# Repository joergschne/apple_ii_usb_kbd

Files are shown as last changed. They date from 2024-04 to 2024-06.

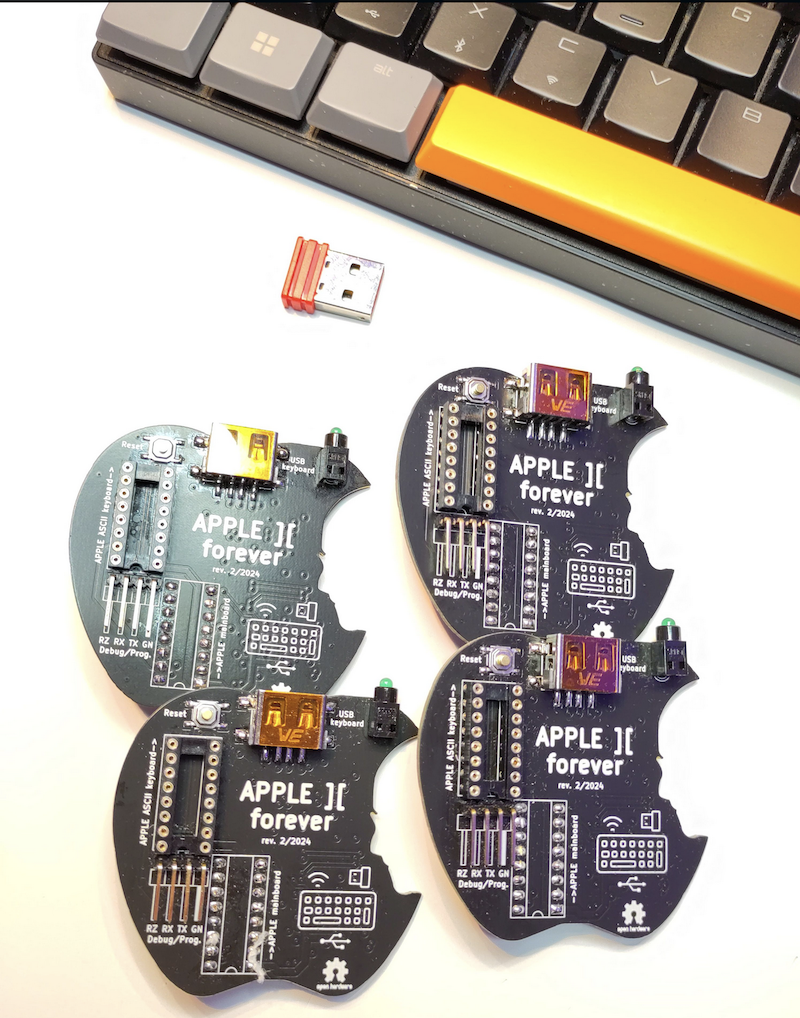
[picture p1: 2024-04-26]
Pictures/produced.png

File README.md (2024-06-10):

# Apple II USB Keyboard-Adapter

Based on Arduino-UNO (ATMEGA328P) and Maxim MAX3421E USB-Host-Controller

- USB keyboard (wireless) with and without NKRO (N-Key-Rollover) support.

- DE and US layouts can be toggled by pressing Windows+1 (US) and Windows+2 (DE). Windows+0 stores the last setting in EEPROM.

- Ctrl+Insert / Ctrl+Alt+Delete performs a hardware reset.

- The Windows key itself switches back to the original Apple keyboard. This is the default setting on power up and the switch to USB is automatic.

- Autorepeat function and the “Up arrow” button repeats the last entry

- Caps Lock (Shift Lock) lower case support

- Win+9 (LodeRunner Mapping) assigns the keys I,J,K,L to W,A,S,D to play an unpatched version of LodeRunner with the usual key combination

- Specially build for: CHERRY MX-LP 2.1 Compact Wireless Keyboard

APPLE II forever! 

Apple

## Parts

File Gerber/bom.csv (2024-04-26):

Designator | Footprint | Quantity | Value | LCSC Part #
C1, C2 | 0805 | 2 | 10uF
C10, C9 | 0805 | 2 | 18pF
C3, C6, C7, C8 | 0805 | 4 | 100n
C4, C5 | 0805 | 2 | 22pF
D1 | LED_D3.0mm | 1 | LED
F1 | 0805 | 1 | 0.75A
J1 | USB-A 629104190121 | 1 | USB-A 629104190121
J2 | PinHeader_1x04_P2.54mm_Horizontal | 1 | Debug
R1, R8, R9 | 0805 | 3 | 2K2
R2, R3 | 0805 | 2 | 33
R4, R5, R6 | 0805 | 3 | 10k
R7 | 0805 | 1 | 100
SW1 | SW_PTS525SM15SMTR2LFS | 1 | Reset
U1 | DIP-16_W7.62mm_Socket_LongPads | 1 | MAINBOARD (OUT)
U2 | DIP-16_W7.62mm_Socket_LongPads | 1 | KEYBOARD (IN)
U3, U4 | SOIC-16_3.9x9.9mm_P1.27mm | 2 | 74x257
U5 | SOIC-16_3.9x9.9mm_P1.27mm | 1 | 74x4050
U6 | TQFP-32_7x7mm_P0.8mm | 1 | ATMEGA328-TQFP
U7 | max3421-TQFP | 1 | USB-Host Controller
U8 | SOT-23 | 1 | MCP1700x-3V3
Y1 | FA238 | 1 | 12Mhz
Y2 | FA238 | 1 | 16Mhz

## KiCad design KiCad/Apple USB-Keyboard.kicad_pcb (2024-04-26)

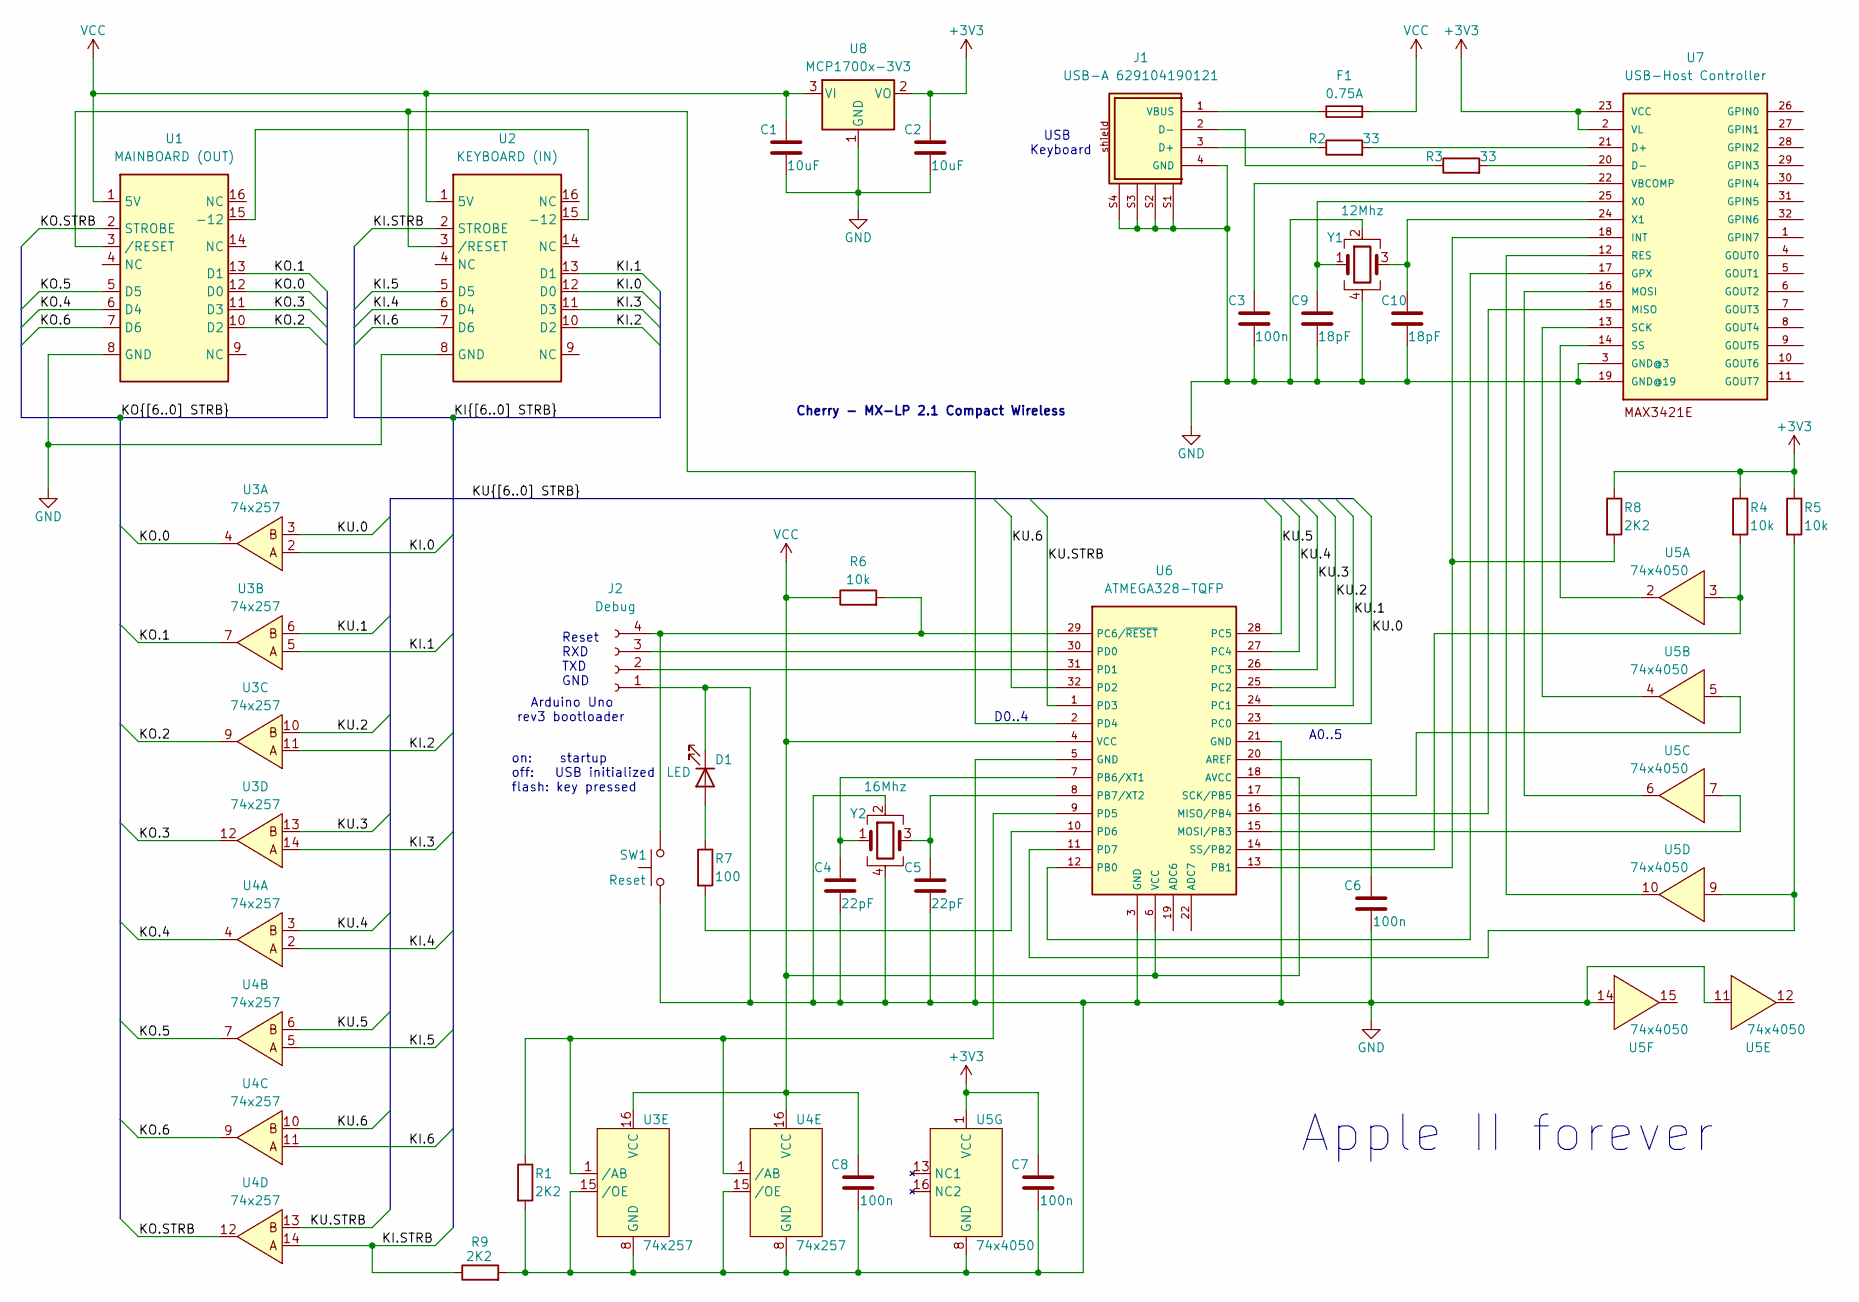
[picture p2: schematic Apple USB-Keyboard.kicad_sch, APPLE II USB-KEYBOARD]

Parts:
C1, C2: 10uF; C_0805_2012Metric_Pad1.18x1.45mm_HandSolder
C3, C6, C7, C8: 100n; C_0805_2012Metric_Pad1.18x1.45mm_HandSolder
C4, C5: 22pF; C_0805_2012Metric_Pad1.18x1.45mm_HandSolder
C9, C10: 18pF; C_0805_2012Metric_Pad1.18x1.45mm_HandSolder
D1: LED; LED_D3.0mm
F1: 0.75A; Fuse_0805_2012Metric_Pad1.15x1.40mm_HandSolder
J1: USB-A 629104190121; PART-NUMBER 629104190121
J2: Debug; PinHeader_1x04_P2.54mm_Horizontal
R1, R8, R9: 2K2; R_0805_2012Metric_Pad1.20x1.40mm_HandSolder
R2, R3: 33; R_0805_2012Metric_Pad1.20x1.40mm_HandSolder
R4, R5, R6: 10k; R_0805_2012Metric_Pad1.20x1.40mm_HandSolder
R7: 100; R_0805_2012Metric_Pad1.20x1.40mm_HandSolder
SW1: Reset; SW_PTS525SM15SMTR2LFS
U1: MAINBOARD (OUT); DIP-16_W7.62mm_Socket_LongPads
U2: KEYBOARD (IN); DIP-16_W7.62mm_Socket_LongPads
U3, U4: 74x257; SOIC-16_3.9x9.9mm_P1.27mm
U5: 74x4050; SOIC-16_3.9x9.9mm_P1.27mm
U6: ATMEGA328-TQFP; TQFP-32_7x7mm_P0.8mm
U7: USB-Host Controller; max3421-TQFP
U8: MCP1700x-3V3; SOT-23
Y1: 12Mhz; FA238
Y2: 16Mhz; FA238

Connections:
+3V3: C2.1, C7.2, R4.1, R5.1, R8.1, U5.1 (VCC), U7.2 (VL), U7.23 (VCC), U8.2 (VO)
/KI.0: U2.12 (D0), U3.2
/KI.1: U2.13 (D1), U3.5
/KI.2: U2.10 (D2), U3.11
/KI.3: U2.11 (D3), U3.14
/KI.4: U2.6 (D4), U4.2
/KI.5: U2.5 (D5), U4.5
/KI.6: U2.7 (D6), U4.11
/KI.STRB: R9.1, U2.2 (STROBE), U4.14
/KO.0: U1.12 (D0), U3.4
/KO.1: U1.13 (D1), U3.7
/KO.2: U1.10 (D2), U3.9
/KO.3: U1.11 (D3), U3.12
/KO.4: U1.6 (D4), U4.4
/KO.5: U1.5 (D5), U4.7
/KO.6: U1.7 (D6), U4.9
/KO.STRB: U1.2 (STROBE), U4.12
/KU.0: U3.3, U6.23 (PC0)
/KU.1: U3.6, U6.24 (PC1)
/KU.2: U3.10, U6.25 (PC2)
/KU.3: U3.13, U6.26 (PC3)
/KU.4: U4.3, U6.27 (PC4)
/KU.5: U4.6, U6.28 (PC5)
/KU.6: U4.10, U6.32 (PD2)
/KU.STRB: U4.13, U6.1 (PD3)
GND: C1.2, C2.2, C3.2, C4.2, C5.2, C6.1, C7.1, C8.1, C9.2, C10.2, D1.1 (K), J1.4 (GND), J1.S1, J1.S2, J1.S3, J1.S4, J2.1, R1.2, R9.2, SW1.1, U1.8 (GND), U2.8 (GND), U3.8 (GND), U3.15 (/OE), U4.8 (GND), U4.15 (/OE), U5.8 (GND), U5.11, U5.14, U6.3 (GND), U6.5 (GND), U6.21 (GND), U7.3 (GND@3), U7.19 (GND@19), U8.1 (GND), Y1.2, Y1.4, Y2.2, Y2.4
unnamed: D1.2 (A), R7.1
unnamed: J1.3 (D+), R2.1
unnamed: J1.2 (D-), R3.1
unnamed: F1.1, J1.1 (VBUS)
unnamed: J2.2, U6.31 (PD1)
unnamed: J2.3, U6.30 (PD0)
unnamed: J2.4, R6.2, SW1.2, U6.29 (PC6/~RESET)
unnamed: U1.15 (-12), U2.15 (-12)
unnamed: U1.3 (/RESET), U2.3 (/RESET), U6.2 (PD4)
unnamed: R1.1, U3.1 (/AB), U4.1 (/AB), U6.9 (PD5)
unnamed: C6.2, U6.20 (AREF)
unnamed: U6.16 (MISO/PB4), U7.15 (MISO)
unnamed: U5.7, U6.15 (MOSI/PB3)
unnamed: U6.12 (PB0), U7.17 (GPX)
unnamed: R8.2, U6.13 (PB1), U7.18 (INT)
unnamed: C4.1, U6.7 (PB6/XT1), Y2.1
unnamed: C5.1, U6.8 (PB7/XT2), Y2.3
unnamed: R7.2, U6.10 (PD6)
unnamed: R5.2, U5.9, U6.11 (PD7)
unnamed: U5.5, U6.17 (SCK/PB5)
unnamed: R4.2, U5.3, U6.14 (SS/PB2)
unnamed: R2.2, U7.21 (D+)
unnamed: R3.2, U7.20 (D-)
unnamed: U5.6, U7.16 (MOSI)
unnamed: U5.10, U7.12 (RES)
unnamed: U5.4, U7.13 (SCK)
unnamed: U5.2, U7.14 (SS)
unnamed: C3.1, U7.22 (VBCOMP)
unnamed: C9.1, U7.25 (X0), Y1.1
unnamed: C10.1, U7.24 (X1), Y1.3
VCC: C1.1, C8.2, F1.2, R6.1, U1.1 (5V), U2.1 (5V), U3.16 (VCC), U4.16 (VCC), U6.4 (VCC), U6.6 (VCC), U6.18 (AVCC), U8.3 (VI)

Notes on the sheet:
D0..4
A0..5
Cherry - MX-LP 2.1 Compact Wireless
USB Keyboard
Arduino Uno rev3 bootloader
Reset RXD TXD GND
on: startup off: USB initialized flash: key pressed
Apple II forever

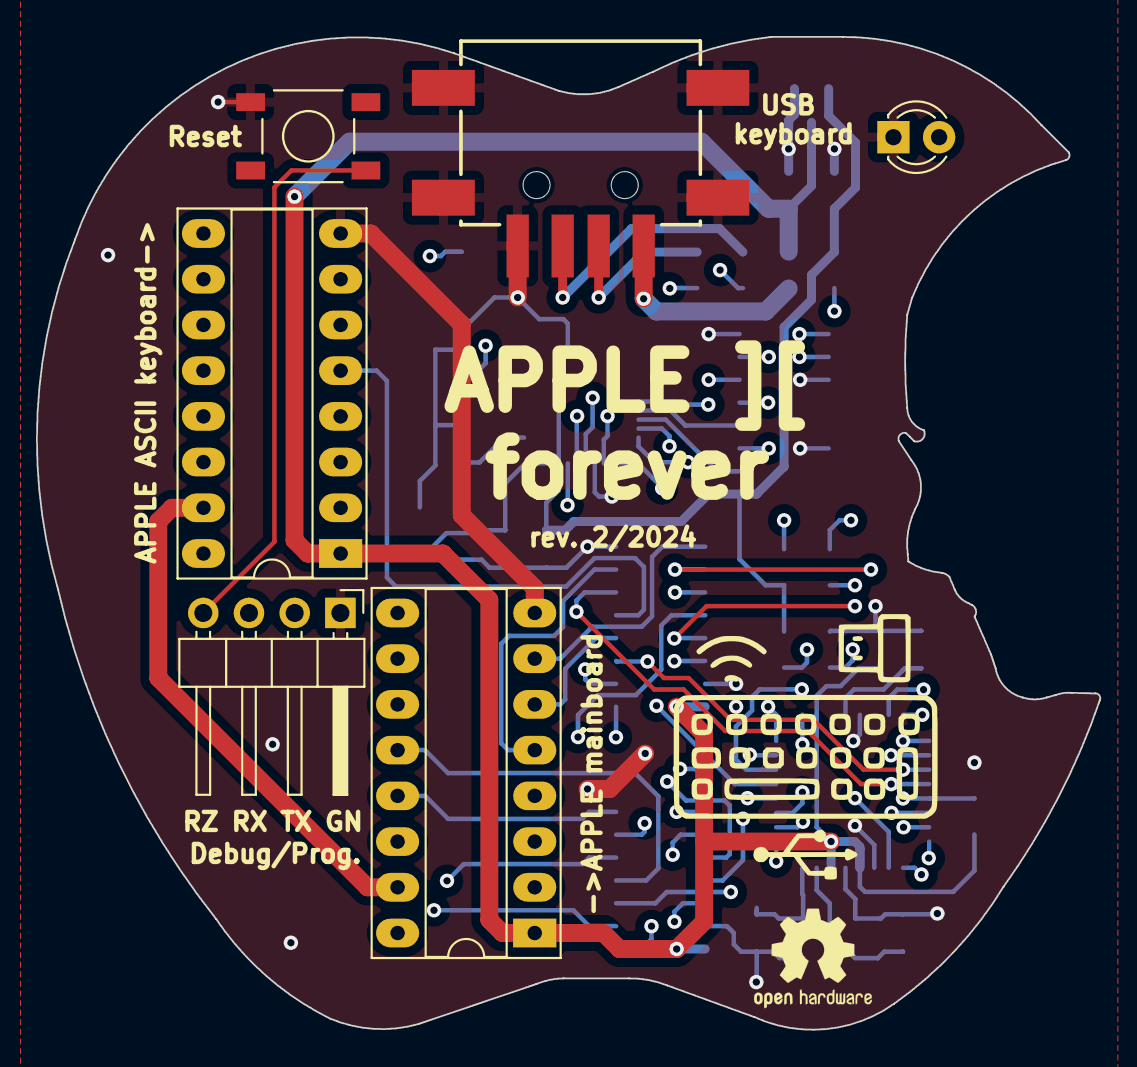
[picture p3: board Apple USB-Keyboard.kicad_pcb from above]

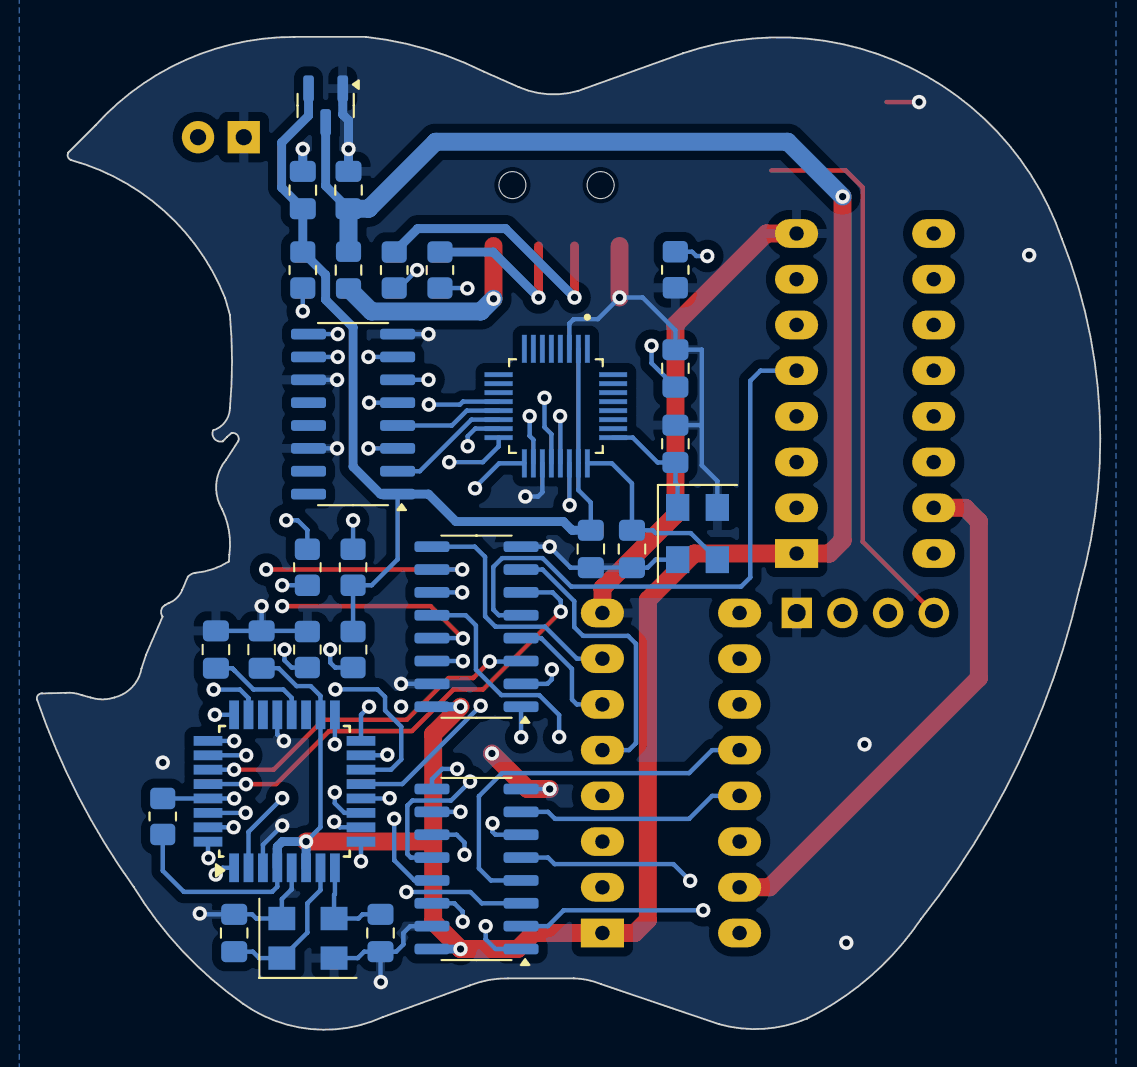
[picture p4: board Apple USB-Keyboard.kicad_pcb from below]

Board: 4 copper layers, 59.1 x 55.2 mm, 34 parts (28 on the bottom side), 57 nets.

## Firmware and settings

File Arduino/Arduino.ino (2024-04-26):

/*
           _____  _____  _____  _      ______   _____ _____ 
      /\   |  __ \|  __ \|  __ \| |    |  ____| |_   _|_   _|
     /  \  | |__) | |__) | |__) | |    | |__      | |   | |  
    / /\ \ |  ___/|  ___/|  ___/| |    |  __|     | |   | |  
   / ____ \| |    | |    | |    | |____| |____   _| |_ _| |_ 
  /_/  __\_\_|____|_|____|_|____|______|______|_|_____|_____|
      |  ____/ __ \|  __ \|  ____\ \    / /  ____|  __ \     
      | |__ | |  | | |__) | |__   \ \  / /| |__  | |__) |    
      |  __|| |  | |  _  /|  __|   \ \/ / |  __| |  _  /     
      | |   | |__| | | \ \| |____   \  /  | |____| | \ \     
      |_|    \____/|_|  \_\______|   \/   |______|_|  \_\    

   APPLE ][ USB-Dual-Keyboard-Adapter (Arduino UNO ATMEAG328P)
                      Version: 04/2024
*/

#include <hidcomposite.h>
#include <usbhub.h>
#include <avr/pgmspace.h>
#include <EEPROM.h>
#include <SPI.h>

#include "Simpletimer.h"

#include "keyboard_encoder.h"
#include "keyboard_decoder.h"

#define PrintDebugInfo true
#define DefaultKeyboardLayout 2 // 1=US 2=DE
#define maxLayout 2

#define REPEAT_INTERVAL_MS 80
#define REPEAT_DELAY 8
#define MAX_REPEAT_BUFFER 64

const char string_0[] PROGMEM = "            _____  _____  _____  _      ______   _____ _____ ";
const char string_1[] PROGMEM = "      /\\   |  __ \\|  __ \\|  __ \\| |    |  ____| |_   _|_   _|";
const char string_2[] PROGMEM = "     /  \\  | |__) | |__) | |__) | |    | |__      | |   | |  ";
const char string_3[] PROGMEM = "    / /\\ \\ |  ___/|  ___/|  ___/| |    |  __|     | |   | |  ";
const char string_4[] PROGMEM = "   / ____ \\| |    | |    | |    | |____| |____   _| |_ _| |_ ";
const char string_5[] PROGMEM = "  /_/  __\\_\\_|____|_|____|_|____|______|______|_|_____|_____|";
const char string_6[] PROGMEM = "      |  ____/ __ \\|  __ \\|  ____\\ \\    / /  ____|  __ \\     ";
const char string_7[] PROGMEM = "      | |__ | |  | | |__) | |__   \\ \\  / /| |__  | |__) |    ";
const char string_8[] PROGMEM = "      |  __|| |  | |  _  /|  __|   \\ \\/ / |  __| |  _  /     ";
const char string_9[] PROGMEM = "      | |   | |__| | | \\ \\| |____   \\  /  | |____| | \\ \\     ";
const char string_A[] PROGMEM = "      |_|    \\____/|_|  \\_\\______|   \\/   |______|_|  \\_\\    ";
const char *const string_table[] PROGMEM = { string_0, string_1, string_2, string_3, string_4, string_5, string_6, string_7, string_8, string_9, string_A };
char buffer[80]; // make sure this is large enough for the largest string it must hold

uint8_t repeatBuffer[MAX_REPEAT_BUFFER] = {};

uint8_t lastKeyPressed = 0;
uint8_t repeatDelay = REPEAT_DELAY;
uint8_t repeatBufferIndex = 0;

boolean lodeRunnerMapping = false;

KeyEncoder KeyEncoder;
KeyDecoder CurrentLayout;
Simpletimer timer1{};

void timerCallback() {
  if (lastKeyPressed){
    if (repeatDelay == 0){
      Serial.println("Autorepeat!");
      KeyEncoder.IIstrobe();
    } else repeatDelay --;
  } else repeatDelay = REPEAT_DELAY;
}

void add2Buffer() {
  repeatBuffer[repeatBufferIndex] = lastKeyPressed;
  if (lastKeyPressed == 0x0D) repeatBufferIndex = 0;
  else if (repeatBufferIndex < MAX_REPEAT_BUFFER) repeatBufferIndex ++;
}

void printBuffer(){
  repeatBufferIndex = 0;
  while ((repeatBuffer[repeatBufferIndex] != 0x0D) && (repeatBufferIndex < MAX_REPEAT_BUFFER)) {
    KeyEncoder.IIputchar((char)repeatBuffer[repeatBufferIndex]);
    delay(50);
    repeatBufferIndex ++;
  }  
}

// Override HIDComposite to be able to select which interface we want to hook into
class HIDSelector : public HIDComposite {
public:
  HIDSelector(USB *p)
    : HIDComposite(p){};

protected:
  void ParseHIDData(USBHID *hid, uint8_t ep, bool is_rpt_id, uint8_t len, uint8_t *buf);  // Called by the HIDComposite library
  bool SelectInterface(uint8_t iface, uint8_t proto);
};

// Return true for the interface we want to hook into
bool HIDSelector::SelectInterface(uint8_t iface, uint8_t proto) {
  if (proto != 0) return true;
  return false;
}

// Will be called for all HID data received from the USB interface
void HIDSelector::ParseHIDData(USBHID *hid, uint8_t ep, bool is_rpt_id, uint8_t len, uint8_t *buf) {

  uint8_t keyCode = 0;

#if PrintDebugInfo
  if (len && buf) {
    Serial.print("USB debug: ");
    for (uint8_t i = 0; i < len; i++) {
      Serial.print(i);
      if (buf[i] == 0x00) Serial.print("-");
      else Serial.print("#");
      if (buf[i] < 0x10) Serial.print("0");
      Serial.print((buf[i] & 0xFF), HEX);
      Serial.print(" ");
    }
    Serial.println("");
  }
#endif
  
  if (len == 21) { // Cherry N-key-rollover USB-keyboard detected
    if (buf[9] & 0x20) CurrentLayout.ToggleCapsLock(); // capsLock
    //if (buf[12] & 0x20) // arrow down
    if (buf[12] & 0x40) printBuffer(); // arrow up
    if (buf[1] & 0x08) {
      KeyEncoder.Disable();
      if (buf[6] & 0x04) { // win 1 = switch keyboard layout to US
        CurrentLayout.SetLayout(1);
        lodeRunnerMapping = false;
        Serial.println("Keyboard layout: US");
      }
      if (buf[6] & 0x08) { // win 2 = switch keyboard layout to DE
        CurrentLayout.SetLayout(2);
        lodeRunnerMapping = false;
        Serial.println("Keyboard layout: DE");
      }
      if (buf[7] & 0x04) { // win 9 = special WASD (NM) mapping for LodeRunner
        lodeRunnerMapping = true;
        Serial.println("Keyboard layout: LodeRunner WASD (NM) special");
      }
      if (buf[7] & 0x08) { // win 0 = save default keyboard
        EEPROM.write(0, CurrentLayout.GetLayout());
        Serial.println("Keyboard layout saved!");
      }  
      buf[6] = 0;
      buf[7] = 0;
    }
    if ((buf[1] & 0x01) && (buf[11] & 0x20)) { // reset 
      KeyEncoder.IIreset();
      Serial.println("Reset!");
    }
    keyCode = CurrentLayout.Decode_NKRO(buf);
    if (keyCode) {
      lastKeyPressed = keyCode;
      add2Buffer();
      if (lodeRunnerMapping) {
        if (keyCode == 0x57) keyCode = 0x49; // W
        if (keyCode == 0x41) keyCode = 0x4A; // A
        if (keyCode == 0x53) keyCode = 0x4B; // S
        if (keyCode == 0x44) keyCode = 0x4C; // D
        if (keyCode == 0x4E) keyCode = 0x55; // N
        if (keyCode == 0x4D) keyCode = 0x4F; // M
      }
      KeyEncoder.IIputchar((char)keyCode);
      Serial.print("NKRO keyCode: 0x");
      Serial.print(keyCode, HEX);
      Serial.println(" ");
    } else lastKeyPressed = 0;
  
 } else { 
  
    if (len == 8) { // other USB-keyboard detected  
      if (buf[2] == 0x39) CurrentLayout.ToggleCapsLock(); // capsLock
      //if (buf[2] == 0x51) // arrow down
      if (buf[2] == 0x52) printBuffer(); // arrow up
      if (buf[0] == 0x08) {
       KeyEncoder.Disable();
       if (buf[2] == 0x1E) { // win 1 = switch keyboard layout to US
         CurrentLayout.SetLayout(1);
         lodeRunnerMapping = false;
         Serial.println("Keyboard layout: US");
       }
       if (buf[2] == 0x1F) { // win 2 = switch keyboard layout to DE
         CurrentLayout.SetLayout(2);
         lodeRunnerMapping = false;
         Serial.println("Keyboard layout: DE");
       }
       if (buf[2] == 0x26) { // win 9 = special WASD (NM) mapping for LodeRunner
        lodeRunnerMapping = true;
        Serial.println("Keyboard layout: LodeRunner WASD (NM) special");
       }
       if (buf[2] == 0x27) { // win 0 = save default keyboard layout
         EEPROM.write(0, CurrentLayout.GetLayout());
         Serial.println("Keyboard layout saved!");
       }
      buf[2] = 0;
      }
      if ((buf[0] == 0x05) && (buf[2] == 0x4C)){ // reset
       KeyEncoder.IIreset();
       Serial.println("Reset!");
      }    
      keyCode = CurrentLayout.Decode_USB(buf);
      if (keyCode) {
        lastKeyPressed = keyCode;
        add2Buffer();
        if (lodeRunnerMapping) {
          if (keyCode == 0x57) keyCode = 0x49; // W
          if (keyCode == 0x41) keyCode = 0x4A; // A
          if (keyCode == 0x53) keyCode = 0x4B; // S
          if (keyCode == 0x44) keyCode = 0x4C; // D
          if (keyCode == 0x4E) keyCode = 0x55; // N
          if (keyCode == 0x4D) keyCode = 0x4F; // M
        }
        KeyEncoder.IIputchar((char)keyCode);
        Serial.print("USB keyCode: 0x");
        Serial.print(keyCode, HEX);
        Serial.println(" ");  
      } else lastKeyPressed = 0;
    }
  }
}

USB Usb;
USBHub     Hub(&Usb);
HIDSelector hidSelector(&Usb);

void setup() {
  KeyEncoder.Init();
  digitalWrite(A2LED, HIGH);

  Serial.begin(115200);
  Serial.println("");
  Serial.println("Welcome to:");
  Serial.println("");

  for (int i = 0; i < 11; i++) {
    strcpy_P(buffer, (char *)pgm_read_word(&(string_table[i]))); // Necessary casts and dereferencing, just copy.
    Serial.println(buffer);
  }
  
  for (int i = 0; i < MAX_REPEAT_BUFFER; i++) {
    repeatBuffer[i] = 0x0D;
  }

  Serial.println("");
  Serial.println("APPLE ][ USB dual Keyboard Adapter: Start-up");

  if (Usb.Init() == -1)
    Serial.println("OSC did not start.");
  else
    digitalWrite(A2LED, LOW);

  // Set this to higher values to enable more debug information
  // minimum 0x00, maximum 0xff, default 0x80
  UsbDEBUGlvl = 0xff;

  CurrentLayout;
  CurrentLayout.ToggleCapsLock();
  if (EEPROM.read(0) > maxLayout) 
    CurrentLayout.SetLayout(DefaultKeyboardLayout);
  else
    CurrentLayout.SetLayout(EEPROM.read(0));
  Serial.print("Current keyboard layout is: ");
  if (CurrentLayout.GetLayout() == 1) 
    Serial.println("US");
  else 
    Serial.println("DE");

  delay(200);
  timer1.register_callback(timerCallback);
}

void loop() {
  timer1.run(REPEAT_INTERVAL_MS);
  Usb.Task();
}

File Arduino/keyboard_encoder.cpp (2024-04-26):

/*! \file II_Encoder.cpp 
 * \brief Output ASCII in parallel form to Apple II keyboard connector.
 *
 *  Takes a ASCII character or string and sets the IO Pins accordingly for APPLE II keayboard Input.
 */

#include "Arduino.h"
#include "keyboard_encoder.h"

void KeyEncoder::Init(void)
{
  pinMode(IIKEYB_D0, OUTPUT);
  pinMode(IIKEYB_D1, OUTPUT);
  pinMode(IIKEYB_D2, OUTPUT);
  pinMode(IIKEYB_D3, OUTPUT);
  pinMode(IIKEYB_D4, OUTPUT);
  pinMode(IIKEYB_D5, OUTPUT);
  pinMode(IIKEYB_D6, OUTPUT);
  pinMode(IIKEYB_RESET, INPUT_PULLUP);
  pinMode(IIKEYB_STRB, OUTPUT);
  pinMode(A2LATCH, OUTPUT);
  pinMode(A2LED, OUTPUT);

  digitalWrite(IIKEYB_STRB, LOW);
  digitalWrite(A2LATCH, LOW);
  digitalWrite(A2LED, LOW);
}

void KeyEncoder::Disable(void)
{
  digitalWrite(IIKEYB_D0, LOW);
  digitalWrite(IIKEYB_D1, LOW);
  digitalWrite(IIKEYB_D2, LOW);
  digitalWrite(IIKEYB_D3, LOW);
  digitalWrite(IIKEYB_D4, LOW);
  digitalWrite(IIKEYB_D5, LOW);
  digitalWrite(IIKEYB_D6, LOW);
  digitalWrite(A2LATCH, LOW);
}

void KeyEncoder::IIreset(void)
{
  digitalWrite(A2LATCH, LOW);
  pinMode(IIKEYB_RESET, OUTPUT);
  digitalWrite(IIKEYB_RESET, LOW);
  delay(10);
  pinMode(IIKEYB_RESET, INPUT_PULLUP);
  digitalWrite(IIKEYB_RESET, HIGH);
}

void KeyEncoder::IIstrobe(void)
{
  digitalWrite(A2LED, HIGH);
  digitalWrite(A2LATCH, HIGH);
  digitalWrite(IIKEYB_STRB, HIGH);
  delay(5);
  digitalWrite(IIKEYB_STRB, LOW);    
  digitalWrite(A2LED, LOW);
}

int KeyEncoder::IIputchar(int bOutput)
{
  if (bOutput & 0b00000001)
    digitalWrite(IIKEYB_D0, HIGH);
  else
    digitalWrite(IIKEYB_D0, LOW);

  if (bOutput & 0b00000010)
    digitalWrite(IIKEYB_D1, HIGH);
  else
    digitalWrite(IIKEYB_D1, LOW);

  if (bOutput & 0b00000100)
    digitalWrite(IIKEYB_D2, HIGH);
  else
    digitalWrite(IIKEYB_D2, LOW);

  if (bOutput & 0b00001000)
    digitalWrite(IIKEYB_D3, HIGH);
  else
    digitalWrite(IIKEYB_D3, LOW);

  if (bOutput & 0b00010000)
    digitalWrite(IIKEYB_D4, HIGH);
  else
    digitalWrite(IIKEYB_D4, LOW);

  if (bOutput & 0b00100000)
    digitalWrite(IIKEYB_D5, HIGH);
  else
    digitalWrite(IIKEYB_D5, LOW);

  if (bOutput & 0b01000000)
    digitalWrite(IIKEYB_D6, HIGH);
  else
    digitalWrite(IIKEYB_D6, LOW);
  
  delay(5);
  IIstrobe();
  return (bOutput);
}

int KeyEncoder::IIputs(const char *string)
{
  int i = 0;
  while (string[i])
  {
    if (IIputchar(string[i]) == EOF)
    {
      return EOF;
    }
    i++;
  }

  if (IIputchar('\r') == EOF)
  {
    return EOF;
  }
  return 1;
}
